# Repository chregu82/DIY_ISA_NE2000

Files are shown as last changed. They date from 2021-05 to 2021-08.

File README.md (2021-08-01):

# DIY_ISA_NE2000
A build yourself ISA NE2000 compatible network card based on the Realtek RTL8019AS controller.
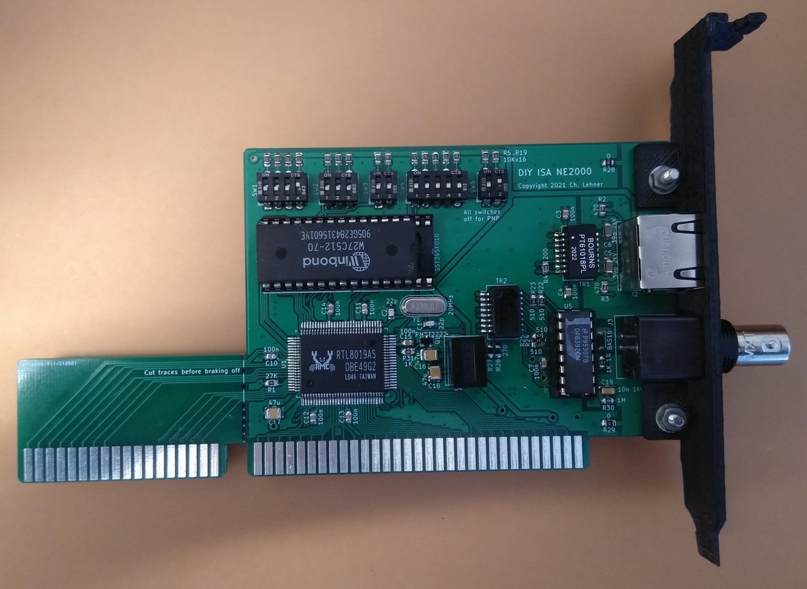
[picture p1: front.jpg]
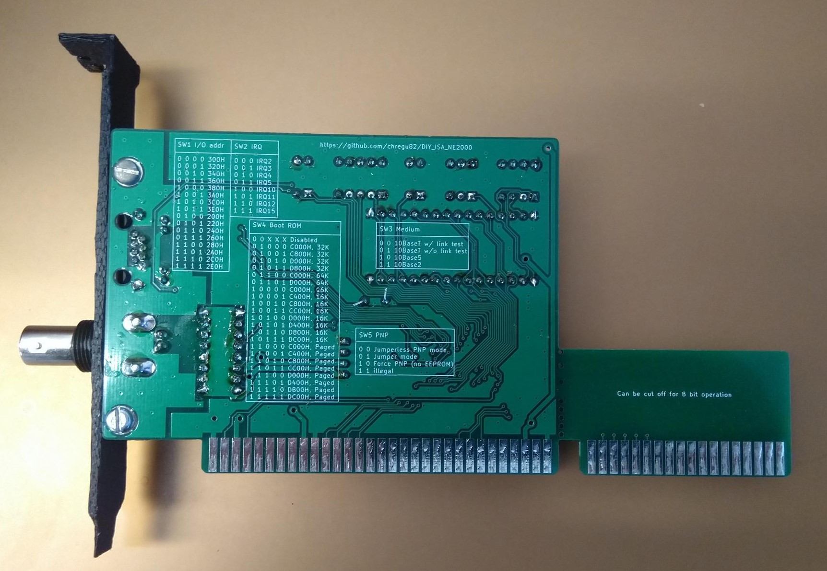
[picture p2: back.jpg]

The PCB is designed to be usable as either an 8 bit or a 16 bit ISA card. If size matters, the 16 bit part can be broken off.
All components should be solderable by hand, although the RTL8019 chip is probably challenging. The smallest resistor or cap is in a 0805 case.
There are several hardware options:
- 10BaseT
- 10Base2
- Dip switch configuration (for pre-PNP computers)
- Boot ROM
## Hardware
### PCB
PCBs can be ordered from your favourite PCB supplier, e.g. JLCPCB or PCBway by using the provided [gerber files](https://github.com/chregu82/DIY_ISA_NE2000/blob/main/PCB/gerber/gerber.zip).
### General parts (use always)
Reference | Quantity | Description | Possible source
------------ | ------------- | -------------- | --------------
C1, C2 | 2 | Capacitor 22pF, 25V, 0805 | [Mouser](https://www.mouser.com/ProductDetail/80-C0805C220K3HACTU), [Reichelt](https://www.reichelt.com/smd-vielschicht-keramikkondensator-22p-5--npo-g0805-22p-p13517.html)
C8, C10-C15 | 7 | Capacitor 0.1uF, 50V, 0805 | [Mouser](https://www.mouser.com/ProductDetail/80-C0805C104M5R), [Reichelt](https://www.reichelt.com/vielschicht-kerko-100nf-50v-125-c-kem-x7r0805-100n-p207073.html)
C17 | 1 | Capacitor 47uF, 16V, 1210 | [Mouser](https://www.mouser.com/ProductDetail/81-GRM32EC81C476KE5L), [Reichelt](https://www.reichelt.com/vielschicht-kerko-47-f-16v-85-c-kem-x5r1210-47u-p207183.html)
R1 | 1 | Resistor 27K, 0805 | [Mouser](https://www.mouser.com/ProductDetail/652-CR0805FX-2702ELF), [Reichelt](https://www.reichelt.com/smd-widerstand-0805-27-kohm-125-mw-1--smd-0805-27-0k-p32903.html)
R28, R29 | 2 | Resistor 0 Ohm, 0805 | [Mouser](https://www.mouser.com/ProductDetail/603-RC0805JR-070RL), [Reichelt](https://www.reichelt.com/smd-widerstand-0805-0-0-ohm-125-mw-rnd-0805-1-0-p212707.html)
U1 | 1 | RTL8019AS | [Aliexpress](https://www.aliexpress.com), [Utsource](https://www.utsource.net/sch/rtl8019as.html), [Reichelt](https://www.reichelt.com/de/de/voll-duplex-ethernet-kontroller-plug-play-funktion-pqfp-100-rtl-8019as-p89309.html)
U2 | 1 | EEPROM 93C46, SOIC-8 | [Mouser](https://www.mouser.com/ProductDetail/556-A93C46DNSH-B), [Reichelt](https://www.reichelt.com/eeprom-seriell-1kb-128x8-64x16-2-5--5-v-so-8-m93c46-wmn6p-p280929.html)
Y1 | 1 | Crystal 20MHz, 18pF, HC49 | [Mouser](https://www.mouser.com/ProductDetail/815-ABL-20-B2), [Reichelt](https://www.reichelt.com/standardquarz-grundton-20-mhz-iqd-lfxtal003181-p245404.html)
### 10BaseT (RJ45)
Reference | Quantity | Description | Possible source
------------ | ------------- | -------------- | --------------
C3, C4 | 2 | Capacitor 0.1uF, 50V, 0805 | [Mouser](https://www.mouser.com/ProductDetail/80-C0805C104M5R), [Reichelt](https://www.reichelt.com/vielschicht-kerko-100nf-50v-125-c-kem-x7r0805-100n-p207073.html)
C5, C6 | 2 | Capacitor 39pF, 2kV, 1206 | [Mouser](https://www.mouser.com/ProductDetail/81-GRM31A7U3D390JW1D)
R2, R3 | 2 | Resistor 470 Ohm, 0805 | [Mouser](https://www.mouser.com/ProductDetail/652-CR0805FX-4700ELF)
R4 | 1 | Resistor 200 Ohm, 0805 | [Mouser](https://www.mouser.com/ProductDetail/652-CR0805FX-2000ELF)
J2 | 1 | RJ45 Connector | [Mouser](https://www.mouser.com/ProductDetail/523-RJHSE-5481)
TR1 | 1 | LAN transformer | [Mouser](https://www.mouser.com/ProductDetail/652-PT61017PEL), [Mouser alternative part](https://www.mouser.ch/ProductDetail/815-ALANS100X12F10ET)
### 10Base2 (BNC)
Reference | Quantity | Description | Possible source
------------ | ------------- | -------------- | --------------
C7 | 1 | Capacitor 0.1uF, 50V, 0805 | [Mouser](https://www.mouser.com/ProductDetail/80-C0805C104M5R), [Reichelt](https://www.reichelt.com/vielschicht-kerko-100nf-50v-125-c-kem-x7r0805-100n-p207073.html)
C19 | 1 | Capacitor 10nF, 1kV, 1206 | [Mouser](https://www.mouser.com/ProductDetail/710-885342208021), [Reichelt](https://www.reichelt.com/ch/de/smd-kerko-1206-10-nf-1000-v-10-mlcc-rnd-1501206b1033-p226057.html)
C16, C18 | 2 | Capacitor 47uF, 16V, 1210 | [Mouser](https://www.mouser.com/ProductDetail/81-GRM32EC81C476KE5L), [Reichelt](https://www.reichelt.com/vielschicht-kerko-47-f-16v-85-c-kem-x5r1210-47u-p207183.html)
D1 | 1 | Diode BAS16, SOD-123 | [Mouser](https://www.mouser.com/ProductDetail/841-BAS16GWJ), [Reichelt](https://www.reichelt.com/gleichrichterdiode-75-v-0-215-a-sot-23-bas-16-nxp-p219347.html)
J3 | 1 | BNC Connector | [Mouser](https://www.mouser.com/ProductDetail/538-73137-5003)
Q1 | 1 | Switching Transistor NPN 600mA, SOT-23 | [Mouser](https://www.mouser.com/ProductDetail/771-PMBT2222A-T-R), [Reichelt](https://www.reichelt.com/bipolartransistor-npn-40v-0-6a-0-33w-sot-23-smbt-2222a-inf-p219350.html)
R30 | 1 | Resistor 1M, 1/2W, 0805 | [Mouser](https://www.mouser.com/ProductDetail/652-CMP0805AFX-1004L)
R21, R31 | 2 | Resistor 1K, 1% , 0805 | [Mouser](https://www.mouser.com/ProductDetail/652-CR0805FX-1001ELF), [Reichelt](https://www.reichelt.com/ch/de/smd-widerstand-0805-1-0-kohm-125-mw-1--smd-0805-1-00k-p32886.html)
R22-R25 | 4 | Resistor 510 Ohm , 0805 | [Mouser](https://www.mouser.ch/ProductDetail/652-CR0805FX-5100ELF), [Reichelt](https://www.reichelt.com/ch/de/smd-widerstand-0805-510-ohm-330-mw-1--rnd-155hp05-di-p250803.html)
R26, R27 | 2 | Resistor 270 Ohm , 0805 | [Mouser](https://www.mouser.ch/ProductDetail/652-CR0805FX-2700ELF)
TR2 | 1 | AUI Transformer | [Mouser](https://www.mouser.com/ProductDetail/673-PE-65728NL), [Mouser alternative](https://www.mouser.ch/ProductDetail/493-TG01-1006NRL)
U4 | 1 | DC-DC Converter 12V to 9V, SIP4 | [Mouser](https://www.mouser.com/ProductDetail/209-IL1209S), [Alternative Mouser, expensive](https://www.mouser.com/ProductDetail/919-RI3-1209S)
U5 | 1 | BNC Transceiver DP8392CN, DIP16 | [Aliexpress](https://www.aliexpress.com), [Utsource](https://www.utsource.net/sch/dp8392cn.html)
### Dip switches (without PNP)
Reference | Quantity | Description | Possible source
------------ | ------------- | -------------- | --------------
R5-R19 | 16 | Resistor 10K , 0805 | [Mouser](https://www.mouser.com/ProductDetail/652-CR0805-JW-103ELF), [Reichelt](https://www.reichelt.com/smd-widerstand-0805-10-kohm-125-mw-1--rnd-0805-1-10k-p183251.html)
SW1 | 1 | Dip switch 4 pos | [Mouser](https://www.mouser.com/ProductDetail/774-2104MS), [Reichelt](https://www.reichelt.com/dip-schalter-liegend-4-polig-nt-04-p13532.html)
SW2 | 1 | Dip switch 3 pos | [Mouser](https://www.mouser.com/ProductDetail/774-2103MS), [Reichelt](https://www.reichelt.com/dip-schalter-liegend-3-polig-nt-03-p36465.html)
SW3, SW5 | 2 | Dip switch 2 pos | [Mouser](https://www.mouser.com/ProductDetail/774-2102MS), [Reichelt](https://www.reichelt.com/dip-schalter-liegend-2-polig-nt-02-p36464.html)
SW4 | 1 | Dip switch 5 pos | [Mouser](https://www.mouser.com/ProductDetail/774-2105MS), [Reichelt](https://www.reichelt.com/dip-schalter-liegend-5-polig-nt-05-p36466.html)
### Boot ROM
Reference | Quantity | Description | Possible source
------------ | ------------- | -------------- | --------------
C9 | 1 | Capacitor 0.1uF, 50V, 0805 | [Mouser](https://www.mouser.com/ProductDetail/80-C0805C104M5R), [Reichelt](https://www.reichelt.com/vielschicht-kerko-100nf-50v-125-c-kem-x7r0805-100n-p207073.html)
U3 | 1 | Socket DIP32, width 15.24mm | [Mouser](https://www.mouser.com/ProductDetail/649-DILB32P223TLF), [Reichelt](https://www.reichelt.com/ic-sockel-32-polig-doppelter-federkontakt-is25t1-332b-p268816.html)
U3 | 1 | Flash 1MBit DIP32 | [Mouser](https://www.mouser.com/ProductDetail/804-39SF010A7CPHE), [Reichelt](https://www.reichelt.com/multi-nor-flash-speicher-1-mb-128-k-x-8-5-v-dip-32-39sf01070-4c-p-p266393.html)
### ISA bracket
The mounting holes in the PCB are designed for the [Keystone 9202 Bracket](https://www.mouser.ch/ProductDetail/534-9202). Holes would have to be cut into the metal. There's no drawing yet.
I designed a 3D printable [ISA bracket](https://github.com/chregu82/DIY_ISA_NE2000/tree/main/Bracket) with holes for 10BaseT and 10Base2.
### 8 bit operation
For 8 bit computers, where size matters, the 16 bit part of the PCB can be broken off. However you have to make sure that the broken off traces don't connect to anything afterwards. It is probably a good idea to cut them before braking off the PCB part.
### Soldering tips
- Flux is probably of help
- You may want to use some kind of magnification
- Check if the pins made a solid connection
- Check for solder bridges
- Go from small to big
- Always check your power rails (at the big caps) for shorts before putting it in your computer
## Programming the EEPROM
Before the card can work in your system, the RTL8019 chip needs a valid initial configuration. This can be done with the DOS tool pg8019.exe.
- Download the files from the [tools directory](https://github.com/chregu82/DIY_ISA_NE2000/tree/main/Tools)
- Make sure address 0x300 is free
- Put the networking card in a free ISA slot
- Boot to DOS
- If you want, edit 8019as.cfg according to your needs (e.g. MAC address)
- Run pg8019.exe
- Turn off your PC

After the EEPROM is programmed you should be able to use the card. Some settings could still be altered with the tool Rset8019.exe.
## Drivers
[DOS packet driver for 8 bit operation](https://github.com/chregu82/DIY_ISA_NE2000/tree/main/Drivers/8%20bit%20packet%20driver)

[DOS packet driver for 16 bit operation](https://github.com/chregu82/DIY_ISA_NE2000/tree/main/Drivers/16%20bit%20packet%20driver)

[Other drivers directly from Realtek](https://www.realtek.com/en/component/zoo/category/rtl8019as-software)

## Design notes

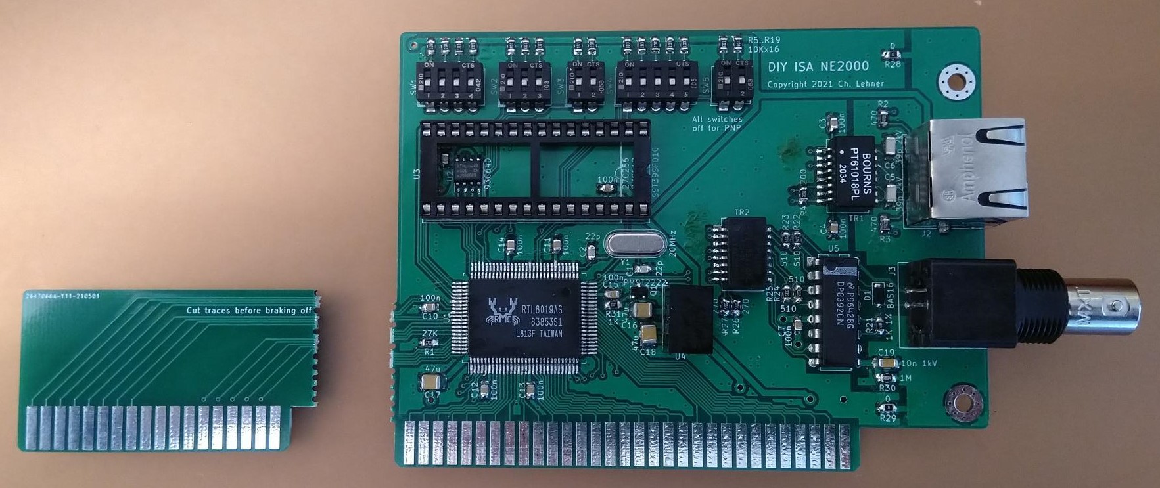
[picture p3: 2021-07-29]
8bit.jpg

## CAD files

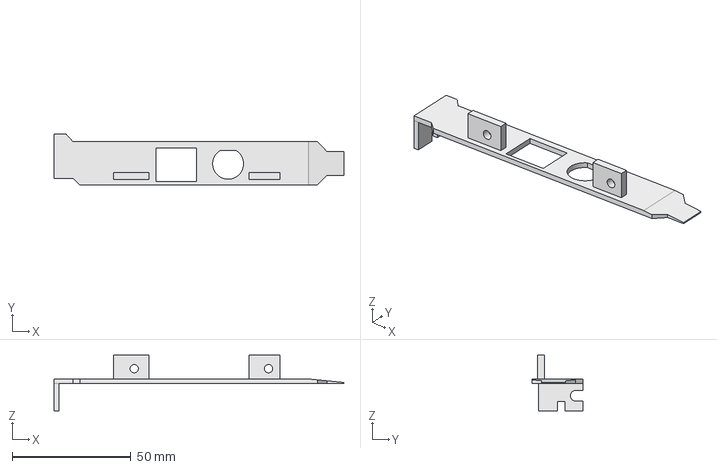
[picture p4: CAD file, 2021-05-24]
Bracket/Bracket.FCStd
122.0 x 21.6 x 23.4 mm

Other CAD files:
Bracket/Bracket.stl

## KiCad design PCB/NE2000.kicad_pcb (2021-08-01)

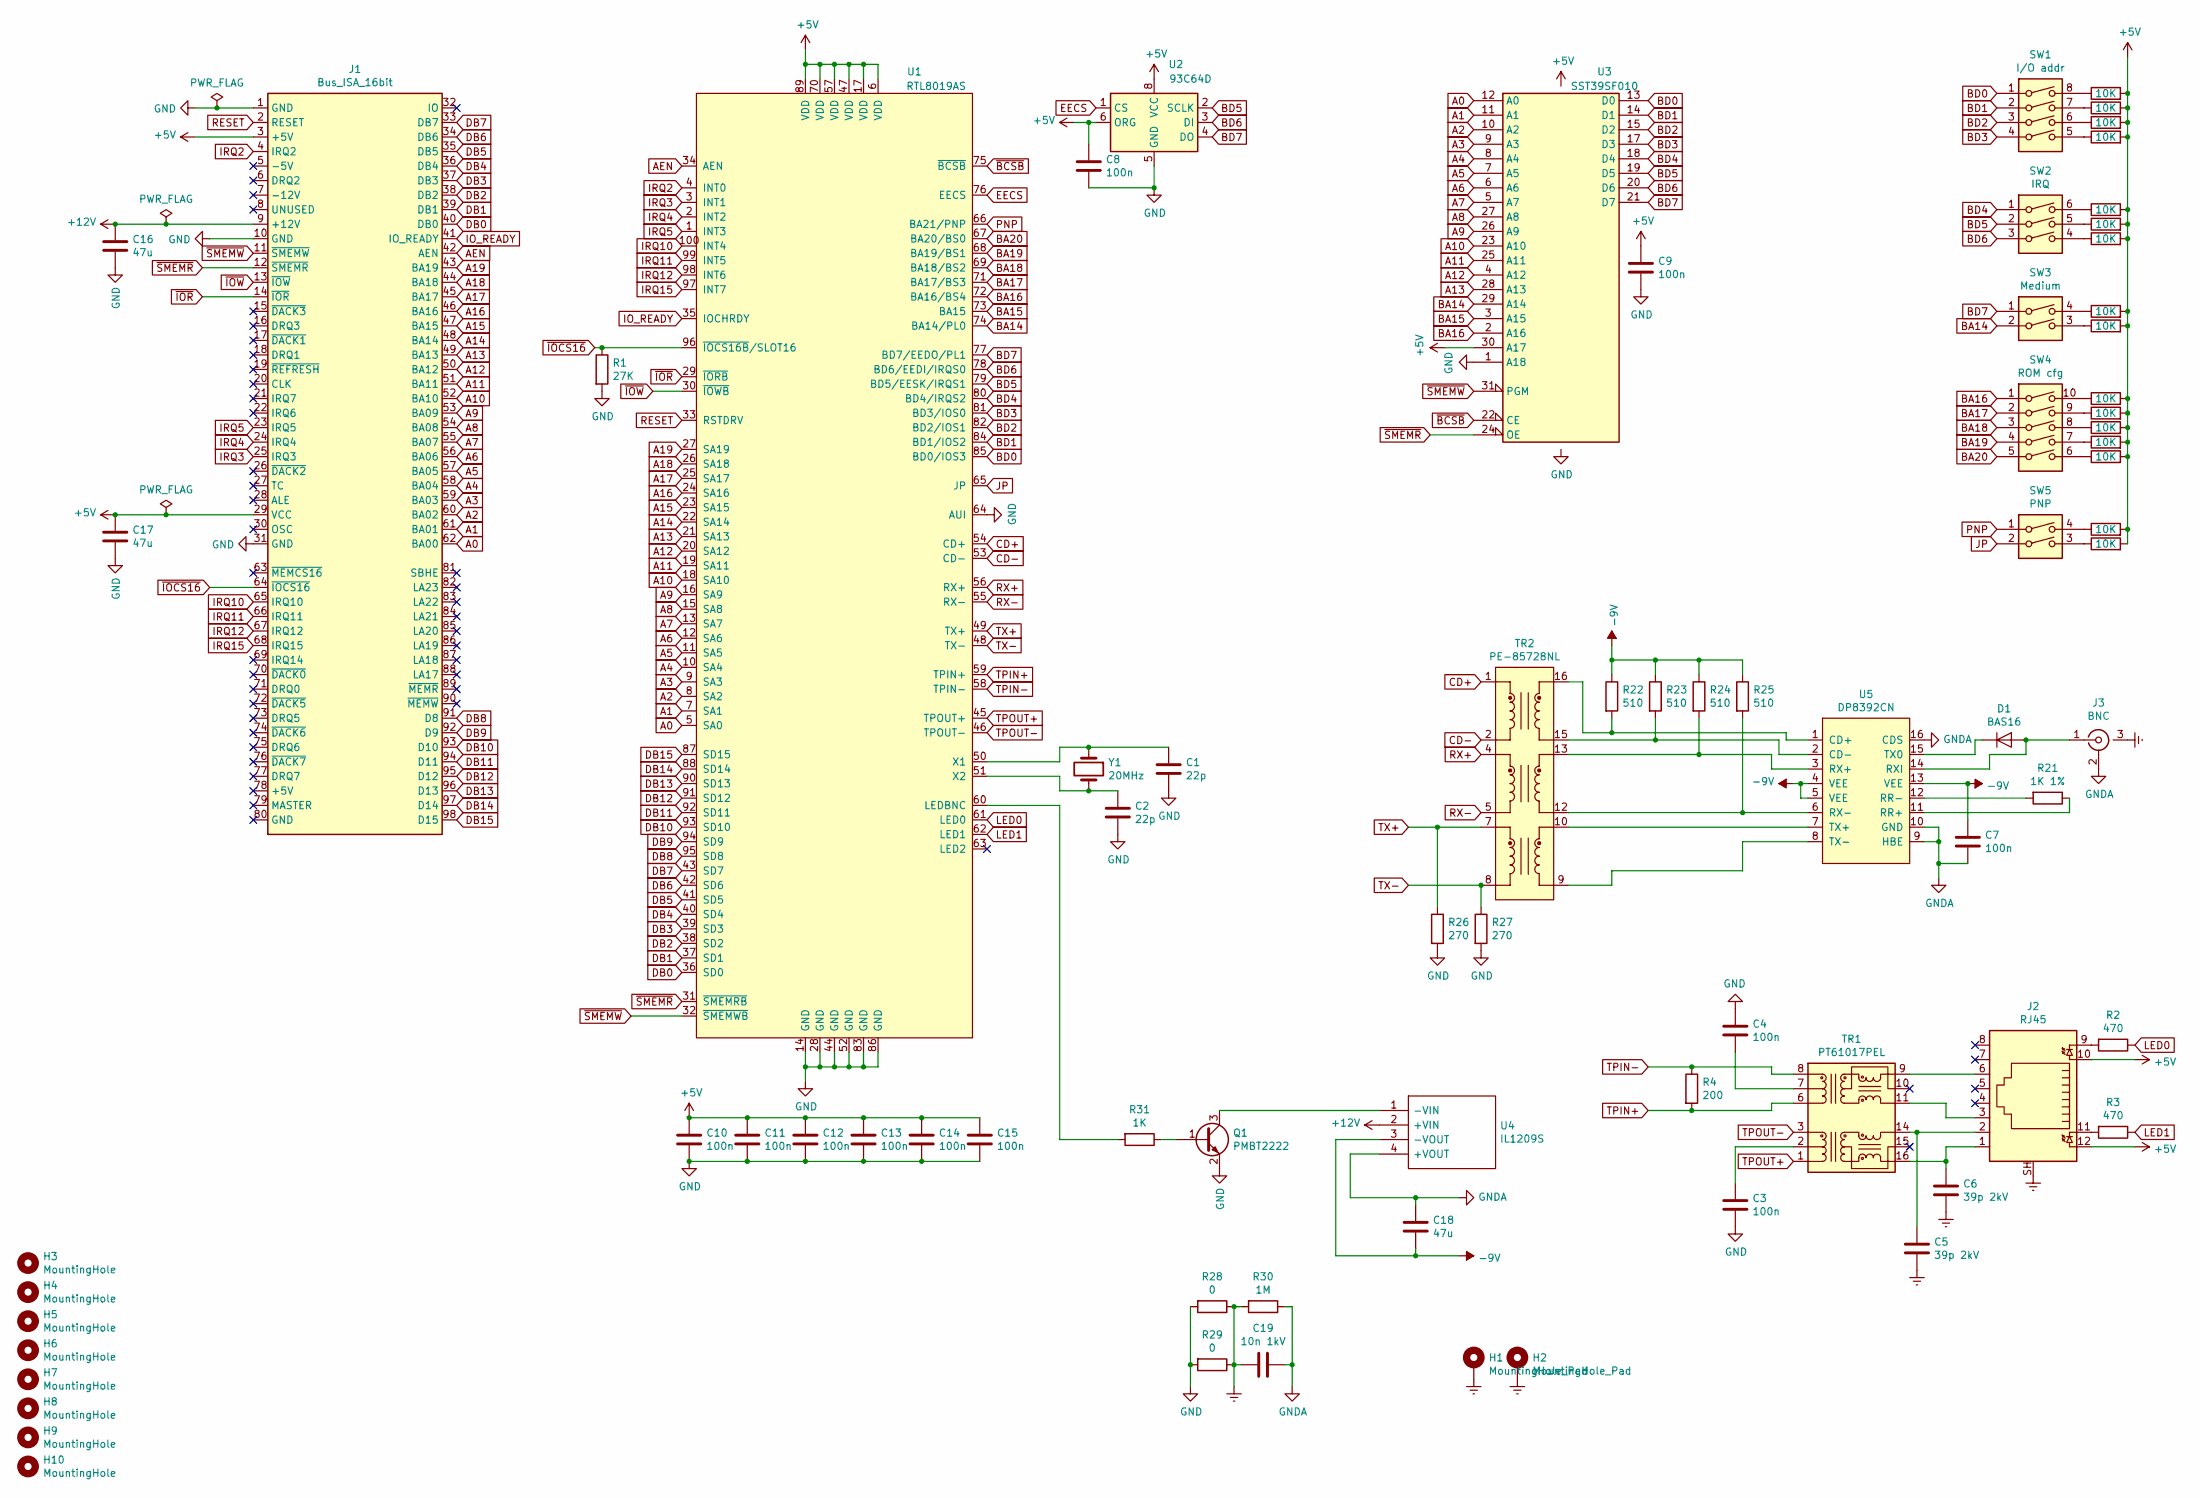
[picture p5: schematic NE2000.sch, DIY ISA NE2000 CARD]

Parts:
C1, C2: 22p; C_0805_2012Metric_Pad1.15x1.40mm_HandSolder; Mouser 80-C0805C220K3HACTU
C3, C4, C7, C8, C9, C10, C11, C12, C13, C14, C15: 100n; C_0805_2012Metric_Pad1.15x1.40mm_HandSolder; Mouser 80-C0805C104M5R
C5, C6: 39p 2kV; C_1206_3216Metric_Pad1.42x1.75mm_HandSolder; Mouser 81-GRM31A7U3D390JW1D
C16, C17, C18: 47u; C_1210_3225Metric_Pad1.42x2.65mm_HandSolder; Mouser 81-GRM32EC81C476KE5L
C19: 10n 1kV; C_1206_3216Metric_Pad1.42x1.75mm_HandSolder; Mouser 710-885342208021
D1: BAS16; D_SOD-123; Mouser 841-BAS16GWJ
H1, H2: MountingHole_Pad; MountingHole_3.2mm_M3_Pad_Via
H3, H4, H5, H6, H7, H8, H9, H10: MountingHole; Cutline
J1: Bus_ISA_16bit; BUS_AT_WO_SILKSCREEN
J2: RJ45; RJ45_Amphenol_RJHSE538X; Mouser 523-RJHSE-5481
J3: BNC; BNC_shield; Mouser 538-73137-5003
Q1: PMBT2222; SOT-23; Mouser 771-PMBT2222A-T/R
R1: 27K; R_0805_2012Metric_Pad1.15x1.40mm_HandSolder; Mouser 652-CR0805FX-2702ELF
R2, R3: 470; R_0805_2012Metric_Pad1.15x1.40mm_HandSolder; Mouser 652-CR0805FX-4700ELF
R4: 200; R_0805_2012Metric_Pad1.15x1.40mm_HandSolder; Mouser 652-CR0805FX-2000ELF
R5, R6, R7, R8, R9, R10, R11, R12, R13, R14, R15, R16, R17, R18, R19, R20: 10K; R_0805_2012Metric_Pad1.15x1.40mm_HandSolder; Mouser 652-CR0805-JW-103ELF
R21: 1K 1%; R_0805_2012Metric_Pad1.15x1.40mm_HandSolder; Mouser 652-CR0805FX-1001ELF
R22, R23, R24, R25: 510; R_0805_2012Metric_Pad1.15x1.40mm_HandSolder; Mouser 603-RC0805JR-07510RL
R26, R27: 270; R_0805_2012Metric_Pad1.15x1.40mm_HandSolder; Mouser 71-CRCW0805270RJNEA
R28, R29: 0; R_0805_2012Metric_Pad1.15x1.40mm_HandSolder; Mouser 603-RC0805JR-070RL
R30: 1M; R_0805_2012Metric_Pad1.15x1.40mm_HandSolder; Mouser 652-CMP0805AFX-1004L
R31: 1K; R_0805_2012Metric_Pad1.15x1.40mm_HandSolder; Mouser 652-CR0805FX-1001ELF
SW1: I/O addr; SW_DIP_SPSTx04_Slide_6.7x11.72mm_W7.62mm_P2.54mm_LowProfile; Mouser 774-2104MS
SW2: IRQ; SW_DIP_SPSTx03_Slide_6.7x9.18mm_W7.62mm_P2.54mm_LowProfile; Mouser 774-2103MS
SW3: Medium; SW_DIP_SPSTx02_Slide_6.7x6.64mm_W7.62mm_P2.54mm_LowProfile; Mouser 774-2102MS
SW4: ROM cfg; SW_DIP_SPSTx05_Slide_6.7x14.26mm_W7.62mm_P2.54mm_LowProfile; Mouser 774-2105MS
SW5: PNP; SW_DIP_SPSTx02_Slide_6.7x6.64mm_W7.62mm_P2.54mm_LowProfile; Mouser 774-2102MS
TR1: PT61017PEL; Transformer_Ethernet_Bourns_PT61017PEL; Mouser 652-PT61017PEL
TR2: PE-85728NL; Transformer_Pulse_H1100NL; Mouser 673-PE-65728NL
U1: RTL8019AS; LQFP-14x20mm_P0.5mm
U2: 93C64D; SOIC-8_3.9x4.9mm_P1.27mm; Mouser 556-A93C46DNSH-B
U3: SST39SF010; DIP32_28; Mouser 649-DILB32P223TLF
U4: IL1209S; DC_DC_12to9; Manufacturer_Part_Number IL1209S; Mouser Part Number 209-IL1209S
U5: DP8392CN; DIP-16_W7.62mm
Y1: 20MHz; Crystal_HC49-U_Vertical; Mouser 815-ABL-20-B2

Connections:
+5V: C8.1, C9.1, C10.1, C11.1, C12.1, C13.1, C14.1, C15.1, C17.1, J1.3 (+5V), J1.29 (VCC), J2.10, J2.12, R5.2, R6.2, R7.2, R8.2, R9.2, R10.2, R11.2, R12.2, R13.2, R14.2, R15.2, R16.2, R17.2, R18.2, R19.2, R20.2, U1.6 (VDD), U1.17 (VDD), U1.47 (VDD), U1.57 (VDD), U1.70 (VDD), U1.89 (VDD), U2.6 (ORG), U2.8 (VCC), U3.30 (A17), U3.32 (VCC)
+12V: C16.1, J1.9 (+12V), U4.2 (+VIN)
-9V: C7.1, C18.2, R22.1, R23.1, R24.1, R25.1, U4.3 (-VOUT), U5.4 (VEE), U5.5 (VEE), U5.13 (VEE)
A0: J1.62 (BA00), U1.5 (SA0), U3.12 (A0)
A1: J1.61 (BA01), U1.7 (SA1), U3.11 (A1)
A2: J1.60 (BA02), U1.8 (SA2), U3.10 (A2)
A3: J1.59 (BA03), U1.9 (SA3), U3.9 (A3)
A4: J1.58 (BA04), U1.10 (SA4), U3.8 (A4)
A5: J1.57 (BA05), U1.11 (SA5), U3.7 (A5)
A6: J1.56 (BA06), U1.12 (SA6), U3.6 (A6)
A7: J1.55 (BA07), U1.13 (SA7), U3.5 (A7)
A8: J1.54 (BA08), U1.15 (SA8), U3.27 (A8)
A9: J1.53 (BA09), U1.16 (SA9), U3.26 (A9)
A10: J1.52 (BA10), U1.18 (SA10), U3.23 (A10)
A11: J1.51 (BA11), U1.19 (SA11), U3.25 (A11)
A12: J1.50 (BA12), U1.20 (SA12), U3.4 (A12)
A13: J1.49 (BA13), U1.21 (SA13), U3.28 (A13)
A14: J1.48 (BA14), U1.22 (SA14)
A15: J1.47 (BA15), U1.23 (SA15)
A16: J1.46 (BA16), U1.24 (SA16)
A17: J1.45 (BA17), U1.25 (SA17)
A18: J1.44 (BA18), U1.26 (SA18)
A19: J1.43 (BA19), U1.27 (SA19)
AEN: J1.42 (AEN), U1.34 (AEN)
BA14: SW3.2, U1.74 (BA14/PL0), U3.29 (A14)
BA15: U1.73 (BA15), U3.3 (A15)
BA16: SW4.1, U1.72 (BA16/BS4), U3.2 (A16)
BA17: SW4.2, U1.71 (BA17/BS3)
BA18: SW4.3, U1.69 (BA18/BS2)
BA19: SW4.4, U1.68 (BA19/BS1)
BA20: SW4.5, U1.67 (BA20/BS0)
BD0: SW1.1, U1.85 (BD0/IOS3), U3.13 (D0)
BD1: SW1.2, U1.84 (BD1/IOS2), U3.14 (D1)
BD2: SW1.3, U1.82 (BD2/IOS1), U3.15 (D2)
BD3: SW1.4, U1.81 (BD3/IOS0), U3.17 (D3)
BD4: SW2.1, U1.80 (BD4/IRQS2), U3.18 (D4)
BD5: SW2.2, U1.79 (BD5/EESK/IRQS1), U2.2 (SCLK), U3.19 (D5)
BD6: SW2.3, U1.78 (BD6/EEDI/IRQS0), U2.3 (DI), U3.20 (D6)
BD7: SW3.1, U1.77 (BD7/EEDO/PL1), U2.4 (DO), U3.21 (D7)
CD+: TR2.1, U1.54 (CD+)
CD-: TR2.2, U1.53 (CD-)
DB0: J1.40 (DB0), U1.36 (SD0)
DB1: J1.39 (DB1), U1.37 (SD1)
DB2: J1.38 (DB2), U1.38 (SD2)
DB3: J1.37 (DB3), U1.39 (SD3)
DB4: J1.36 (DB4), U1.40 (SD4)
DB5: J1.35 (DB5), U1.41 (SD5)
DB6: J1.34 (DB6), U1.42 (SD6)
DB7: J1.33 (DB7), U1.43 (SD7)
DB8: J1.91 (D8), U1.95 (SD8)
DB9: J1.92 (D9), U1.94 (SD9)
DB10: J1.93 (D10), U1.93 (SD10)
DB11: J1.94 (D11), U1.92 (SD11)
DB12: J1.95 (D12), U1.91 (SD12)
DB13: J1.96 (D13), U1.90 (SD13)
DB14: J1.97 (D14), U1.88 (SD14)
DB15: J1.98 (D15), U1.87 (SD15)
EECS: U1.76 (EECS), U2.1 (CS)
Earth: C5.2, C6.2, C19.2, H1.1, H2.1, J2.SH, J3.3, R28.1, R29.1, R30.2
GND: C1.2, C2.2, C3.2, C4.1, C8.2, C9.2, C10.2, C11.2, C12.2, C13.2, C14.2, C15.2, C16.2, C17.2, J1.1 (GND), J1.10 (GND), J1.31 (GND), Q1.2 (E), R1.2, R26.2, R27.2, R28.2, R29.2, U1.14 (GND), U1.28 (GND), U1.44 (GND), U1.52 (GND), U1.64 (AUI), U1.83 (GND), U1.86 (GND), U2.5 (GND), U3.1 (A18), U3.16 (GND)
GNDA: C7.2, C18.1, C19.1, J3.2, R30.1, U4.4 (+VOUT), U5.9 (HBE), U5.10 (GND), U5.16 (CDS)
IO_READY: J1.41 (IO_READY), U1.35 (IOCHRDY)
IRQ2: J1.4 (IRQ2), U1.4 (INT0)
IRQ3: J1.25 (IRQ3), U1.3 (INT1)
IRQ4: J1.24 (IRQ4), U1.2 (INT2)
IRQ5: J1.23 (IRQ5), U1.1 (INT3)
IRQ10: J1.65 (IRQ10), U1.100 (INT4)
IRQ11: J1.66 (IRQ11), U1.99 (INT5)
IRQ12: J1.67 (IRQ12), U1.98 (INT6)
IRQ15: J1.68 (IRQ15), U1.97 (INT7)
JP: SW5.2, U1.65 (JP)
LED0: R2.1, U1.61 (LED0)
LED1: R3.1, U1.62 (LED1)
unnamed: C1.1, U1.50 (X1), Y1.1
unnamed: C2.1, U1.51 (X2), Y1.2
unnamed: C3.1, TR1.2 (C_TD)
unnamed: C4.2, TR1.7 (C_RD)
unnamed: C5.1, J2.2, TR1.14 (TX-)
unnamed: C6.1, J2.1, TR1.16 (TX+)
unnamed: D1.1 (K), U5.15 (TX0)
unnamed: D1.2 (A), J3.1, U5.14 (RXI)
unnamed: J2.3, TR1.11 (RX+)
unnamed: J2.6, TR1.9 (RX-)
unnamed: J2.9, R2.2
unnamed: J2.11, R3.2
unnamed: Q1.1 (B), R31.1
unnamed: Q1.3 (C), U4.1 (-VIN)
unnamed: R5.1, SW1.8
unnamed: R6.1, SW1.7
unnamed: R7.1, SW1.6
unnamed: R8.1, SW1.5
unnamed: R9.1, SW2.6
unnamed: R10.1, SW2.5
unnamed: R11.1, SW2.4
unnamed: R12.1, SW3.4
unnamed: R13.1, SW3.3
unnamed: R14.1, SW4.10
unnamed: R15.1, SW4.9
unnamed: R16.1, SW4.8
unnamed: R17.1, SW4.7
unnamed: R18.1, SW4.6
unnamed: R19.1, SW5.4
unnamed: R20.1, SW5.3
unnamed: R21.1, U5.11 (RR+)
unnamed: R21.2, U5.12 (RR-)
unnamed: R22.2, TR2.16, U5.1 (CD+)
unnamed: R23.2, TR2.15, U5.2 (CD-)
unnamed: R24.2, TR2.13, U5.3 (RX+)
unnamed: R25.2, TR2.12, U5.6 (RX-)
unnamed: R31.2, U1.60 (LEDBNC)
unnamed: TR2.9, U5.8 (TX-)
unnamed: TR2.10, U5.7 (TX+)
PNP: SW5.1, U1.66 (BA21/PNP)
RESET: J1.2 (RESET), U1.33 (RSTDRV)
RX+: TR2.4, U1.56 (RX+)
RX-: TR2.5, U1.55 (RX-)
TPIN+: R4.2, TR1.6 (RD+), U1.59 (TPIN+)
TPIN-: R4.1, TR1.8 (RD-), U1.58 (TPIN-)
TPOUT+: TR1.1 (TD+), U1.45 (TPOUT+)
TPOUT-: TR1.3 (TD-), U1.46 (TPOUT-)
TX+: R26.1, TR2.7, U1.49 (TX+)
TX-: R27.1, TR2.8, U1.48 (TX-)
~BCSB: U1.75 (~BCSB), U3.22 (CE)
~IOCS16: J1.64 (~IOCS16), R1.1, U1.96 (~IOCS16B~/SLOT16)
~IOR: J1.14 (~IOR), U1.29 (~IORB)
~IOW: J1.13 (~IOW), U1.30 (~IOWB)
~SMEMR: J1.12 (~SMEMR), U1.31 (~SMEMRB), U3.24 (OE)
~SMEMW: J1.11 (~SMEMW), U1.32 (~SMEMWB), U3.31 (PGM)

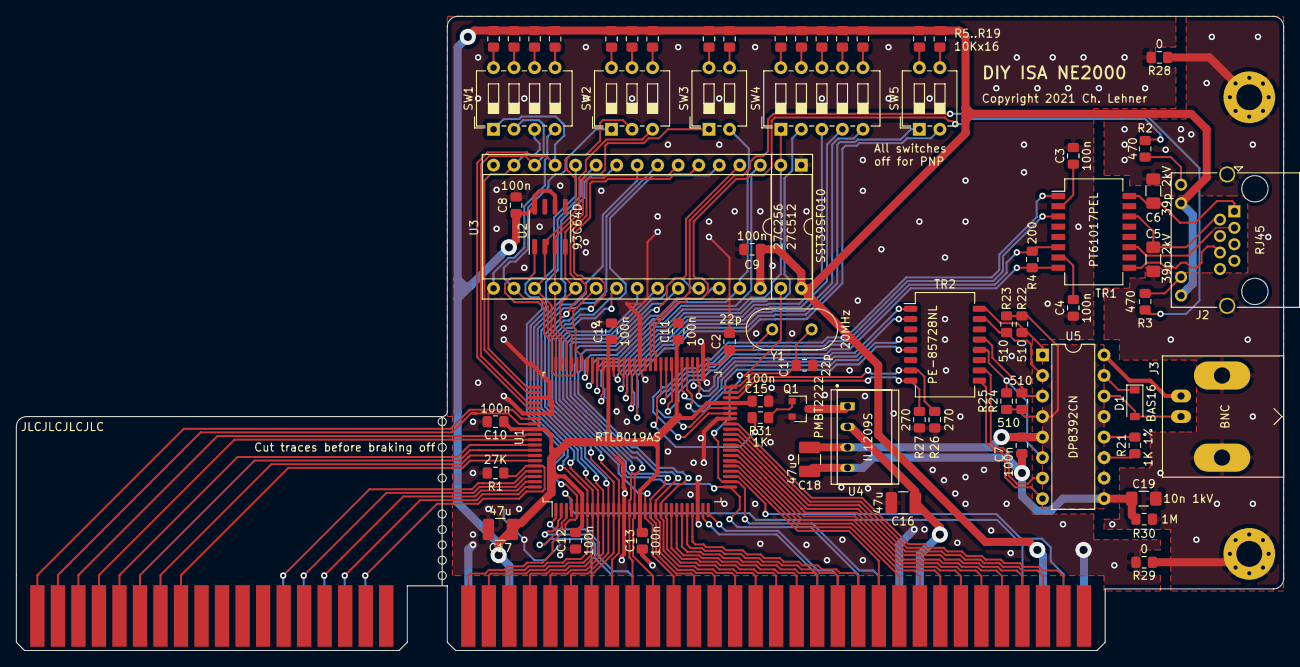
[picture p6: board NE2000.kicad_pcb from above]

Board: 2 copper layers, 156.8 x 78.5 mm, 78 parts (0 on the bottom side), 128 nets.

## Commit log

2021-04-05 PCB work in progress
    [NE2000.kicad_pcb, NE2000.sch]
2021-04-08 Work in progress
    [NE2000.kicad_pcb, NE2000.sch]
2021-04-13 Minor changes
    [NE2000.kicad_pcb, NE2000.sch]
2021-04-25 Use different DC/DC converter
    [NE2000.kicad_pcb, NE2000.sch]
2021-04-30 Updated Gerbers
    [NE2000-B_Cu.gbr, NE2000-B_Mask.gbr, NE2000-B_Paste.gbr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]
2021-05-22 Added sample boot rom
2021-05-24 Bracket V1
    [Bracket.FCStd, Bracket.stl]
2021-05-24 Improved bracket
    [Bracket.FCStd, Bracket.stl]
2021-07-28 Added tools, cleaned up unneeded things
    [8019.CFG, 8019as.cfg]
2021-07-29 Description of bracket and soldering
2021-08-01 Added gerber zip file
2021-08-01 Added packet drivers
2021-08-01 Moved C16 and Q1 for better soldering
    [NE2000-B_Cu.gbr, NE2000-B_Mask.gbr, NE2000-B_Paste.gbr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]

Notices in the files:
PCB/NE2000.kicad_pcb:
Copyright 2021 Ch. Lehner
